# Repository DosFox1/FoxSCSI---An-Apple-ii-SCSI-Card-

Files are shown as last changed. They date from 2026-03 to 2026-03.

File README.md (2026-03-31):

# FoxSCSI - An Apple ii SCSI Card 
An open source clone of the Apple ii SCSI Card. Through hole and done in two layers!


(Many thanks to HKZ for testing this VDEV1 Prototype design)

Apple ii SCSI Low Res Top Side
Apple ii SCSI Low Res Bottom Side

# So what is it?

This is a recreation of the original Apple SCSI Rev C Card for the Apple II.
The equations for the SCSI card were found, converted to GALs, and tested with an original Rev C card.

Additionally, the schematics and ROM for the Rev C card are available online (added in this repository for completeness).
This board is two layer to reduce costs (five boards, finished in ENIG should be about £30 or £6 per board), and is fully through hole.
A 2.85v active termination voltage regulator is added but is not required. 

HKZ is working on an SMD variant of the SCSI card:
https://codeberg.org/hkzlab/AppleII_SCSI_RevC_schematics

# Note Regarding the Board Status
The initial VDEV1 board was tested by HKZ, and three issues were found:
1) a missing connection from IOSEL to the 74LS08
2) A missing "ghost" 330pf capacitor present on the actual boards, but not the transcribed schematics
3) Capacitors were initially noted to be 33pf, actual values should be 330pf.

With these changes, the board successfully booted a DELTA (Apple IIe clone using GALs in place of custom logic - https://codeberg.org/hkzlab/NE_Delta_Schematics).
The latest gerbers have fixes these issues, and should work as is. 

NOTE THAT THEY HAVE NOT BEEN BUILT YET. YOUR MILEAGE MAY VARY!

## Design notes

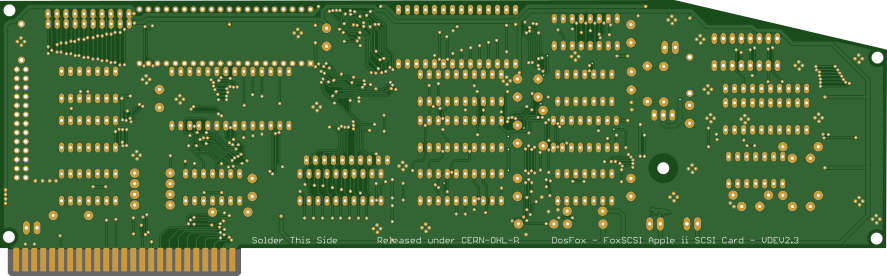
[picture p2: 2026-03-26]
Renders/Apple ii SCSI Low Res Bottom Side.png

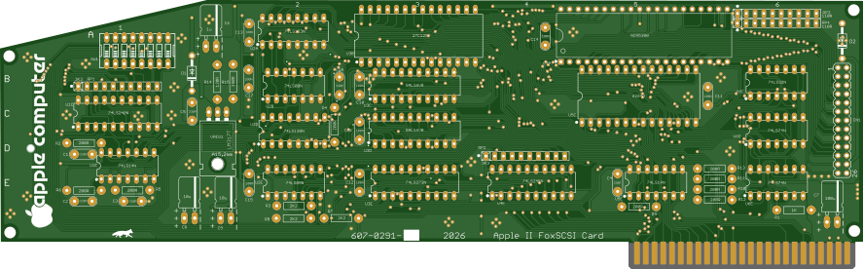
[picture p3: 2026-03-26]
Renders/Apple ii SCSI Low Res Top Side.png

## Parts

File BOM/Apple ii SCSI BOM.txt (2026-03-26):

Partlist

Exported from Apple ii SCSI VDEV2.sch at 25/Mar/26 09:02

EAGLE Version 9.6.2 Copyright (c) 1988-2020 Autodesk, Inc.

Assembly variant: 

Part     Value          Device                     Package               Library           Sheet

C1       330p 100V      330P_TH_CAP                 CAP_5.08MM_PITCH      Capacitors TH     1
C2       330p 100V      330P_TH_CAP                 CAP_5.08MM_PITCH      Capacitors TH     1
C3       330p 100V      330P_TH_CAP                 CAP_5.08MM_PITCH      Capacitors TH     1
C4       330p 100V      330P_TH_CAP                 CAP_5.08MM_PITCH      Capacitors TH     1
C5       330p 50V       330P_TH_CAP                CAP_5.08MM_PITCH      Capacitors TH     1
C6       1u 50V         1U_TH_ELEC_CAPHORIZONTAL   CAP_ELECTROLYTIC_FLAT Capacitors TH     1
C7       100U 50v       100U_TH_ELEC_CAPHORIZONTAL CAP_ELECTROLYTIC_FLAT Capacitors TH     1
C8       10U 50v        10U_TH_ELEC_CAPHORIZONTAL  CAP_ELECTROLYTIC_FLAT Capacitors TH     1
C9       10U 50v        10U_TH_ELEC_CAPHORIZONTAL  CAP_ELECTROLYTIC_FLAT Capacitors TH     1
C10      100n 50V       100N_TH_CAP                CAP_5.08MM_PITCH      Capacitors TH     1
C11      100n 50V       100N_TH_CAP                CAP_5.08MM_PITCH      Capacitors TH     1
C12      100n 50V       100N_TH_CAP                CAP_5.08MM_PITCH      Capacitors TH     1
C13      100n 50V       100N_TH_CAP                CAP_5.08MM_PITCH      Capacitors TH     1
C14      100n 50V       100N_TH_CAP                CAP_5.08MM_PITCH      Capacitors TH     1
C15      100n 50V       100N_TH_CAP                CAP_5.08MM_PITCH      Capacitors TH     1
C16      100n 50V       100N_TH_CAP                CAP_5.08MM_PITCH      Capacitors TH     1
C17      100n 50V       100N_TH_CAP                CAP_5.08MM_PITCH      Capacitors TH     1
C18      330p 100V      33P_TH_CAP                 CAP_5.08MM_PITCH      Capacitors TH     1
CN1      2x13 header    MA13-2                     MA13-2                con-lstb          1
D1       1N4004         1N4004                     DO41-10               adafruit          1
D2       1N4004         1N4004                     DO41-10               adafruit          1
R1       1k             1K_TH_RESISTOR             RESISTORTHRUHOLE      Resistors TH      1
R2       200R           200R_TH_RESISTOR           RESISTORTHRUHOLE      Resistors TH      1
R3       2k2            2K2_TH_RESISTOR            RESISTORTHRUHOLE      Resistors TH      1
R4       200R           200R_TH_RESISTOR           RESISTORTHRUHOLE      Resistors TH      1
R5       200R           200R_TH_RESISTOR           RESISTORTHRUHOLE      Resistors TH      1
R6       200R           200R_TH_RESISTOR           RESISTORTHRUHOLE      Resistors TH      1
R7       2k2            2K2_TH_RESISTOR            RESISTORTHRUHOLE      Resistors TH      1
R8       2k2            2K2_TH_RESISTOR            RESISTORTHRUHOLE      Resistors TH      1
R9       200R           200R_TH_RESISTOR           RESISTORTHRUHOLE      Resistors TH      1
R10      200R           200R_TH_RESISTOR           RESISTORTHRUHOLE      Resistors TH      1
R11      200R           200R_TH_RESISTOR           RESISTORTHRUHOLE      Resistors TH      1
R12      200R           200R_TH_RESISTOR           RESISTORTHRUHOLE      Resistors TH      1
R13      200R           200R_TH_RESISTOR           RESISTORTHRUHOLE      Resistors TH      1
R14      120R           120R_TH_RESISTOR           RESISTORTHRUHOLE      Resistors TH      1
R15      150R           150R_TH_RESISTOR           RESISTORTHRUHOLE      Resistors TH      1
RP1      3K3            RN09                       RN-10                 resistor-net      1
RP2      3K3            RN09                       RN-10                 resistor-net      1
RP3      100R           RN09                       RN-10                 resistor-net      1
RP4      100R           RN09                       RN-10                 resistor-net      1
SW1      8xDip Switch   DIP-08-PTH                 DIPSWITCH-08          SparkFun-Switches 1
U1C      74LS240N       74LS240N                   DIL20                 74xx-us           1
U1E      74LS14N        74LS14N                    DIL14                 74xx-us           1
U2A      74LS133N       74LS133N                   DIL16                 74xx-us           1
U2B      74LS08N        74LS08N                    DIL14                 74xx-us           1
U2D      74LS138N       74LS138N                   DIL16                 74xx-us           1
U2E      74LS09N        74LS09N                    DIL14                 74xx-us           1
U3B      27C128P        27C128P                    DIL28-6               microchip         1
U3C      GAL16V8        ATF16V8BP3                 DIL20                 atmel             1
U3D      GAL16V8        ATF16V8BP3                 DIL20                 atmel             1
U3E      74LS273N       74273N                     DIL20                 74xx-eu           1
U4E      74LS245N       74LS245N                   DIL20                 74xx-us           1
U5A      NCR5380        NCR5380                    DIP40                 ICs               1
U5C      6264A          6264A                      DIL28-6               memory-hitachi    1
U5E      74LS14N        74LS14N                    DIL14                 74xx-us           1
U6C      74LS32N        74LS32N                    DIL14                 74xx-us           1
U6D      74LS74N        74LS74N                    DIL14                 74xx-us           1
U6E      74LS74N        74LS74N                    DIL14                 74xx-us           1
VREG1    LM317T         LM317TL                    317TL                 v-reg             1

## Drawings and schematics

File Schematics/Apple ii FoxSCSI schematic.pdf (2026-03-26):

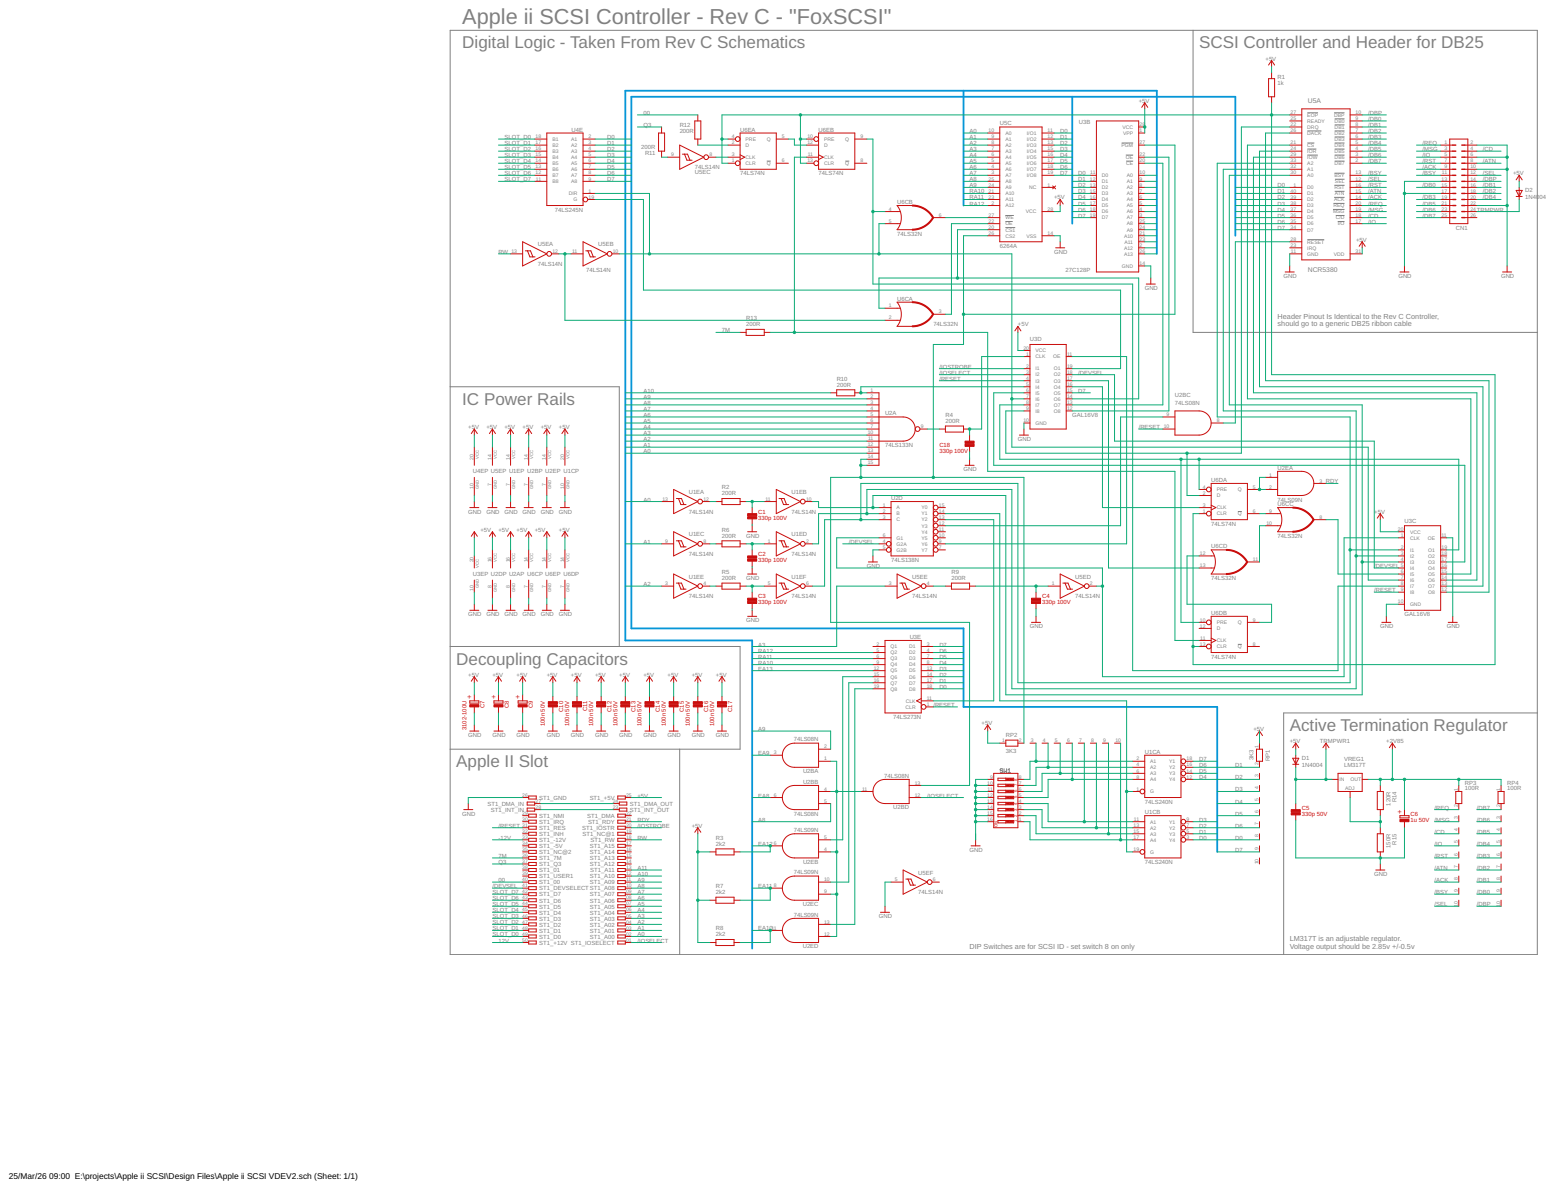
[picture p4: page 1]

Apple ii SCSI Controller - Rev C - "FoxSCSI"

Digital Logic - Taken From Rev C Schematics

SCSI Controller and Header for DB25

Header Pinout Is Identical to the Rev C Controller, should go to a generic DB25 ribbon cable

A4
A3 10

A1 12
13 A0

GND GND GND GND GND

GND GND GND

12 /IOSELECT | 11 | | 6

25/Mar/26 09:00 E:\projects\Apple ii SCSI\Design Files\Apple ii SCSI VDEV2.sch (Sheet: 1/1)

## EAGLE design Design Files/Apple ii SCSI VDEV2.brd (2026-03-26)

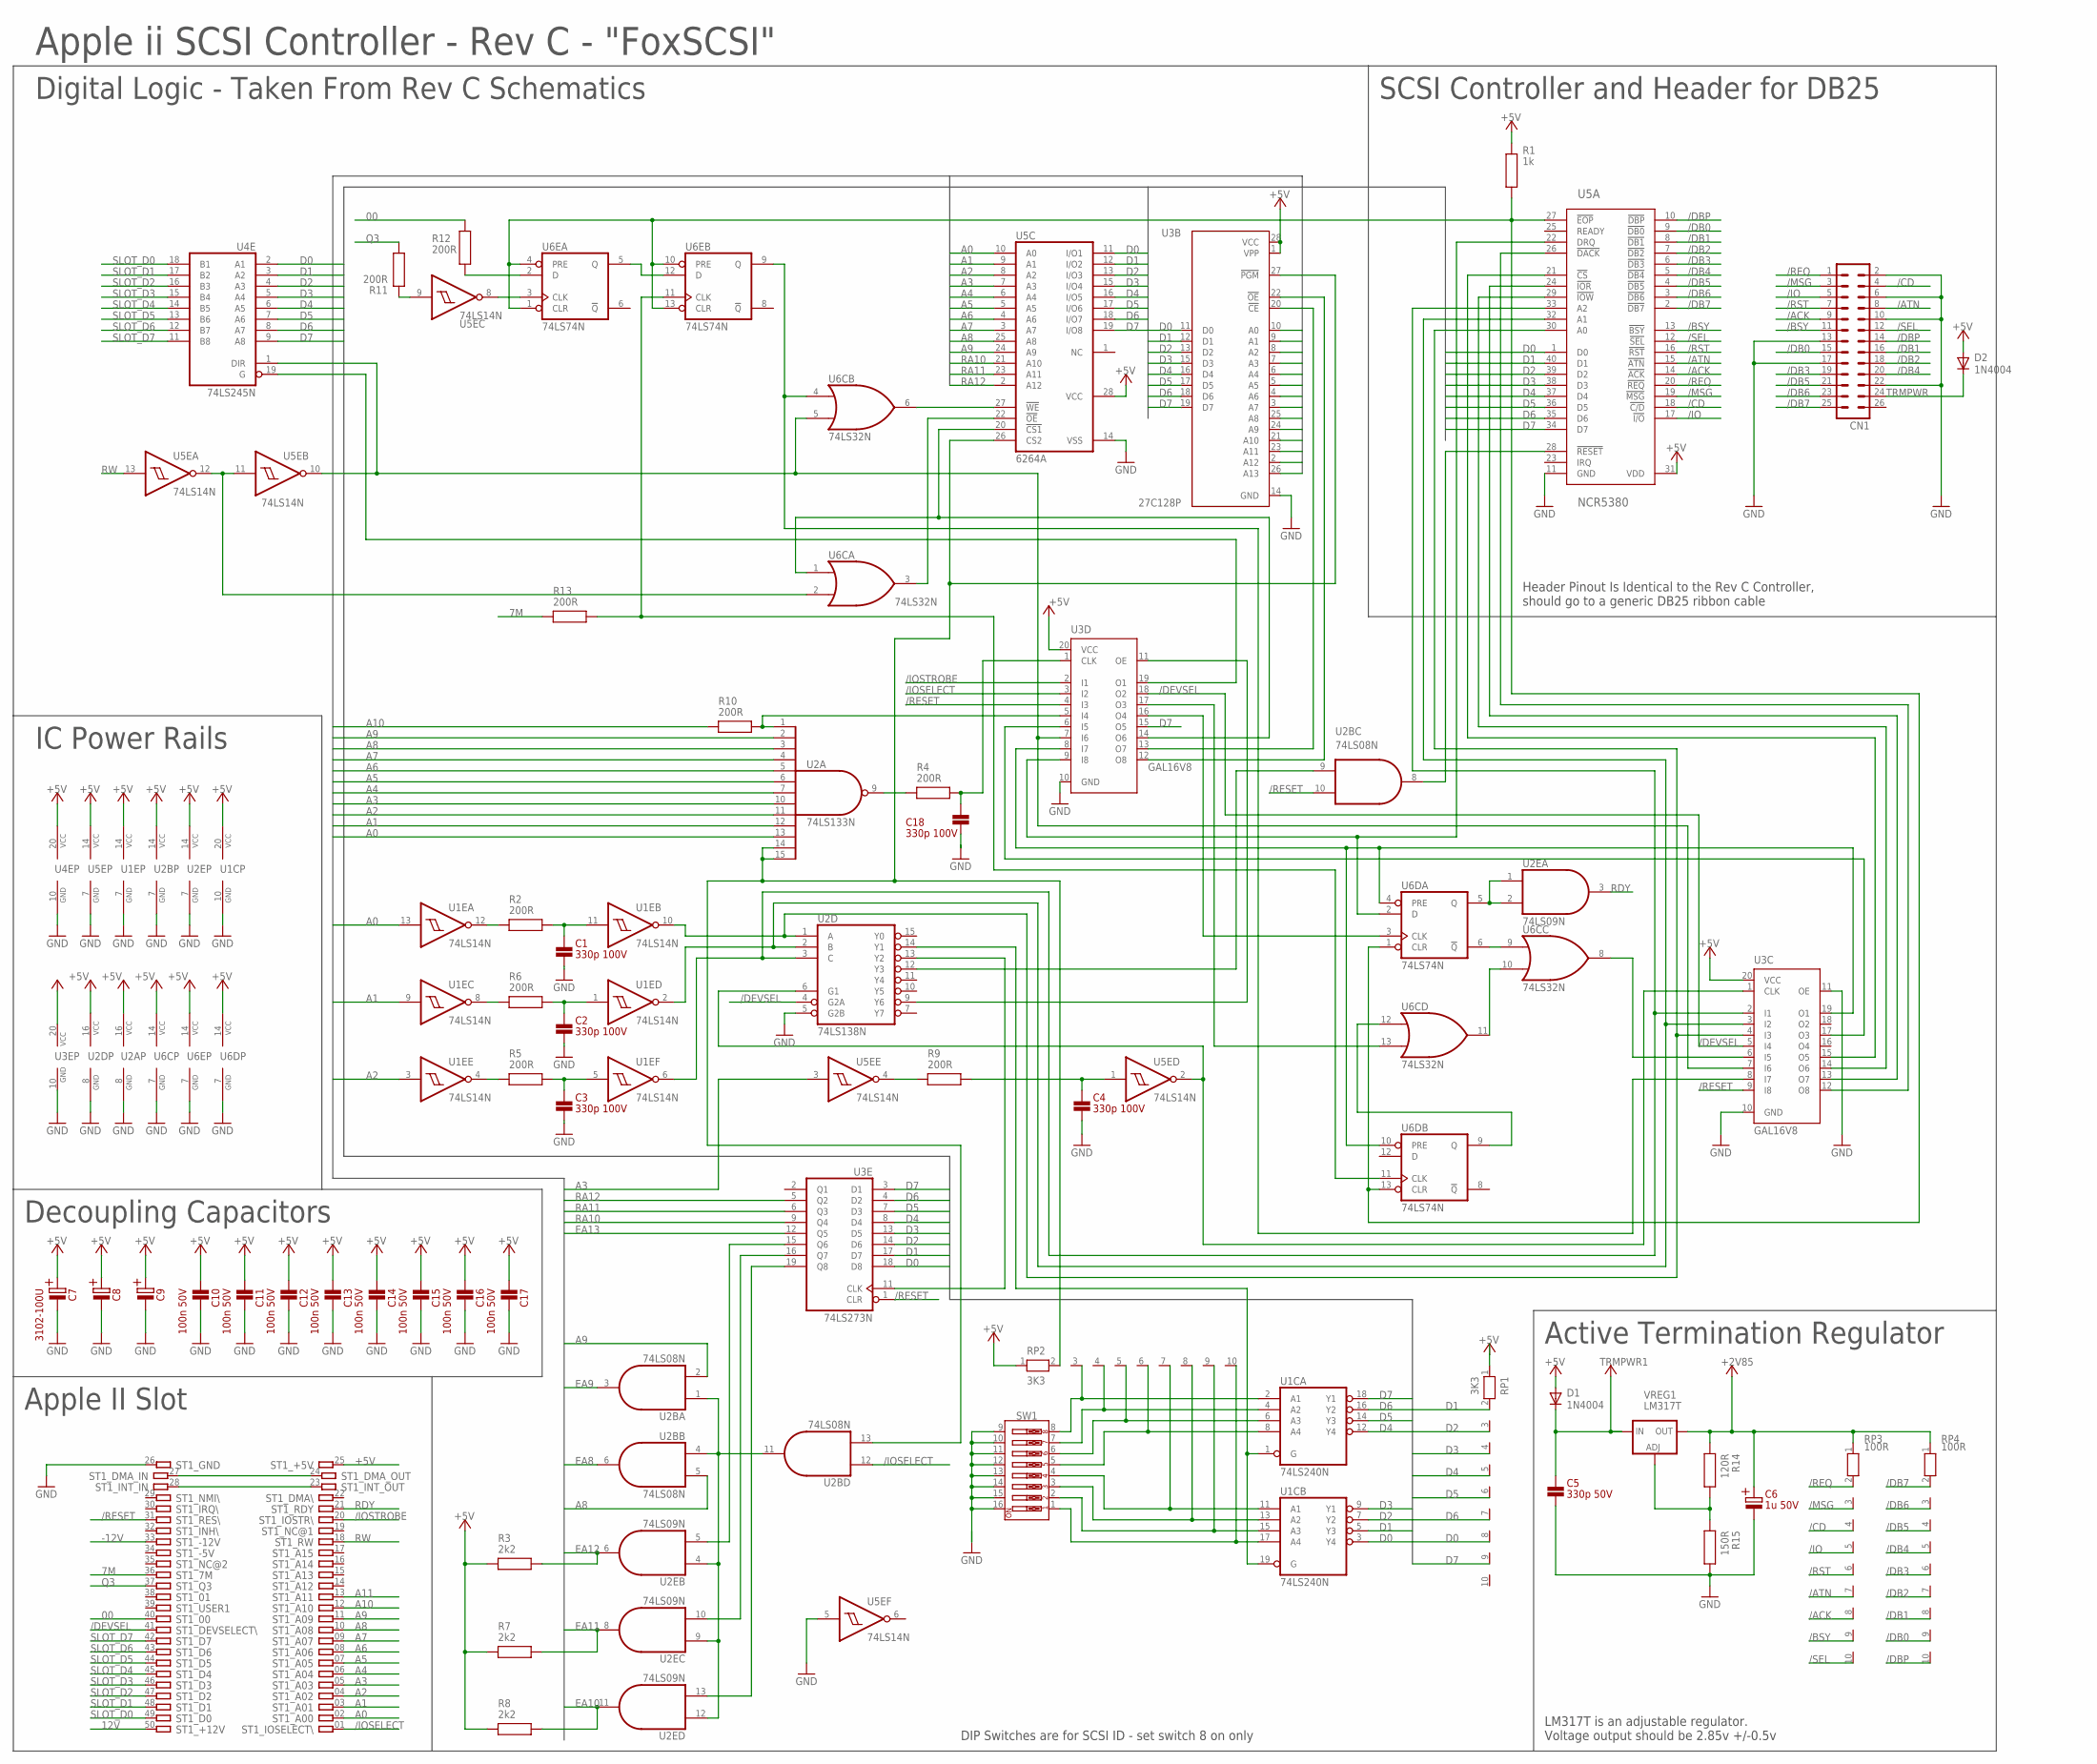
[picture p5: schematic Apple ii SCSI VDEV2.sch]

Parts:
C1, C2, C3, C4, C18: 330p 100V; CAP_5.08MM_PITCH
C5: 330p 50V; CAP_5.08MM_PITCH
C6: 1u 50V; CAP_ELECTROLYTIC_FLAT
C7: 3102-100U; CAP_ELECTROLYTIC_FLAT
C8, C9: 10U_TH_ELEC_CAPHORIZONTAL; CAP_ELECTROLYTIC_FLAT
C10, C11, C12, C13, C14, C15, C16, C17: 100n 50V; CAP_5.08MM_PITCH
CN1: MA13-2
D1, D2: 1N4004; DO41-10
R1: 1k; RESISTORTHRUHOLE
R2, R4, R5, R6, R9, R10, R11, R12, R13: 200R; RESISTORTHRUHOLE
R3, R7, R8: 2k2; RESISTORTHRUHOLE
R14: 120R; RESISTORTHRUHOLE
R15: 150R; RESISTORTHRUHOLE
RP1, RP2: 3K3; RN-10
RP3, RP4: 100R; RN-10
ST1: A2-50PINMINI; A2-50PIN-MINI
SW1: DIP-08-PTH; DIPSWITCH-08
U1C: 74LS240N; DIL20
U1E, U5E: 74LS14N; DIL14
U2A: 74LS133N; DIL16
U2B: 74LS08N; DIL14
U2D: 74LS138N; DIL16
U2E: 74LS09N; DIL14
U3B: 27C128P; DIL28-6
U3C, U3D: GAL16V8; DIL20
U3E: 74LS273N; DIL20
U4E: 74LS245N; DIL20
U5A: NCR5380; DIP40
U5C: 6264A; DIL28-6
U6C: 74LS32N; DIL14
U6D, U6E: 74LS74N; DIL14
VREG1: LM317T; 317TL

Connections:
00: R12.P$2, ST1.40
7M: R13.P$1, ST1.36
12V: ST1.50
+2V85: C6.P$1, R14.P$1, RP3.1, RP4.1, VREG1.2 (OUT)
+5V: C7.P$1, C8.P$1, C9.P$1, C10.P$1, C11.P$1, C12.P$1, C13.P$1, C14.P$1, C15.P$1, C16.P$1, C17.P$1, D1.A, D2.A, R1.P$2, R3.P$1, R7.P$1, R8.P$1, RP1.1, RP2.1, ST1.25, U1C.20 (VCC), U1E.14 (VCC), U2A.16 (VCC), U2B.14 (VCC), U2D.16 (VCC), U2E.14 (VCC), U3B.1 (VPP), U3B.28 (VCC), U3C.20 (VCC), U3D.20 (VCC), U3E.20 (VCC), U4E.20 (VCC), U5A.31 (VDD), U5C.28 (VCC), U5E.14 (VCC), U6C.14 (VCC), U6D.14 (VCC), U6E.14 (VCC)
-12V: ST1.33
/ACK: CN1.9, RP3.8, U5A.14 (!ACK)
/ATN: CN1.8, RP3.7, U5A.15 (!ATN)
/BSY: CN1.11, RP3.9, U5A.13 (!BSY)
/CD: CN1.4, RP3.4, U5A.18 (!C/D)
/DB0: CN1.15, RP4.9, U5A.9 (!DB0)
/DB1: CN1.16, RP4.8, U5A.8 (!DB1)
/DB2: CN1.18, RP4.7, U5A.7 (!DB2)
/DB3: CN1.19, RP4.6, U5A.6 (!DB3)
/DB4: CN1.20, RP4.5, U5A.5 (!DB4)
/DB5: CN1.21, RP4.4, U5A.4 (!DB5)
/DB6: CN1.23, RP4.3, U5A.3 (!DB6)
/DB7: CN1.25, RP4.2, U5A.2 (!DB7)
/DBP: CN1.14, RP4.10, U5A.10 (!DBP)
/DEVSEL: ST1.41, U2D.4 (G2A), U3C.5 (I4), U3D.18 (O2)
/IO: CN1.5, RP3.5, U5A.17 (!I/O)
/IOSELECT: ST1.01, U2B.12 (I0), U3D.3 (I2)
/IOSTROBE: ST1.20, U3D.2 (I1)
/MSG: CN1.3, RP3.3, U5A.19 (!MSG)
/REQ: CN1.1, RP3.2, U5A.20 (!REQ)
/RESET: ST1.31, U2B.10 (I1), U3C.9 (I8), U3D.4 (I3), U3E.1 (CLR)
/RST: CN1.7, RP3.6, U5A.16 (!RST)
/SEL: CN1.12, RP3.10, U5A.12 (!SEL)
A0: ST1.02, U1E.13 (I), U2A.13 (I10), U3B.10 (A0), U5C.10 (A0)
A1: ST1.03, U1E.9 (I), U2A.12 (I9), U3B.9 (A1), U5C.9 (A1)
A2: ST1.04, U1E.3 (I), U2A.11 (I8), U3B.8 (A2), U5C.8 (A2)
A3: ST1.05, U2A.10 (I7), U3B.7 (A3), U5C.7 (A3), U5E.3 (I)
A4: ST1.06, U2A.7 (I6), U3B.6 (A4), U5C.6 (A4)
A5: ST1.07, U2A.6 (I5), U3B.5 (A5), U5C.5 (A5)
A6: ST1.08, U2A.5 (I4), U3B.4 (A6), U5C.4 (A6)
A7: ST1.09, U2A.4 (I3), U3B.3 (A7), U5C.3 (A7)
A8: ST1.10, U2A.3 (I2), U2B.5 (I1), U5C.25 (A8)
A9: ST1.11, U2A.2 (I1), U2B.2 (I1), U5C.24 (A9)
A10: R10.P$1, ST1.12
A11: ST1.13
D0: RP1.8, U1C.3 (Y4), U3B.11 (D0), U3E.18 (D8), U4E.2 (A1), U5A.1 (D0), U5C.11 (I/O1)
D1: RP1.2, U1C.5 (Y3), U3B.12 (D1), U3E.17 (D7), U4E.3 (A2), U5A.40 (D1), U5C.12 (I/O2)
D2: RP1.3, U1C.7 (Y2), U3B.13 (D2), U3E.14 (D6), U4E.4 (A3), U5A.39 (D2), U5C.13 (I/O3)
D3: RP1.4, U1C.9 (Y1), U3B.15 (D3), U3E.13 (D5), U4E.5 (A4), U5A.38 (D3), U5C.15 (I/O4)
D4: RP1.5, U1C.12 (Y4), U3B.16 (D4), U3E.8 (D4), U4E.6 (A5), U5A.37 (D4), U5C.16 (I/O5)
D5: RP1.6, U1C.14 (Y3), U3B.17 (D5), U3E.7 (D3), U4E.7 (A6), U5A.36 (D5), U5C.17 (I/O6)
D6: RP1.7, U1C.16 (Y2), U3B.18 (D6), U3E.4 (D2), U4E.8 (A7), U5A.35 (D6), U5C.18 (I/O7)
D7: RP1.9, U1C.18 (Y1), U3B.19 (D7), U3D.15 (O5), U3E.3 (D1), U4E.9 (A8), U5A.34 (D7), U5C.19 (I/O8)
EA8: U2B.6 (O), U3B.25 (A8)
EA9: U2B.3 (O), U3B.24 (A9)
EA10: R8.P$2, U2E.11 (O), U3B.21 (A10)
EA11: R7.P$2, U2E.8 (O), U3B.23 (A11)
EA12: R3.P$2, U2E.6 (O), U3B.2 (A12)
EA13: U3B.26 (A13), U3E.12 (Q5)
GND: C1.P$1, C2.P$1, C3.P$1, C4.P$1, C5.P$1, C6.P$2, C7.P$2, C8.P$2, C9.P$2, C10.P$2, C11.P$2, C12.P$2, C13.P$2, C14.P$2, C15.P$2, C16.P$2, C17.P$2, C18.P$1, CN1.2, CN1.6, CN1.10, CN1.13, CN1.17, CN1.22, R15.P$2, ST1.26, SW1.9, SW1.10, SW1.11, SW1.12, SW1.13, SW1.14, SW1.15, SW1.16, U1C.10 (GND), U1E.7 (GND), U2A.8 (GND), U2B.7 (GND), U2D.5 (G2B), U2D.8 (GND), U2E.7 (GND), U3B.14 (GND), U3C.10 (GND), U3C.11 (OE), U3D.10 (GND), U3E.10 (GND), U4E.10 (GND), U5A.11 (GND), U5C.14 (VSS), U5E.5 (I), U5E.7 (GND), U6C.7 (GND), U6D.7 (GND), U6E.7 (GND)
unnamed: ST1.24, ST1.27
unnamed: ST1.23, ST1.28
unnamed: U5E.11 (I), U5E.12 (O), U6C.2 (I1)
unnamed: U2B.8 (O), U5A.28 (!RESET)
unnamed: RP2.3, SW1.8, U1C.2 (A1)
unnamed: RP2.4, SW1.7, U1C.4 (A2)
unnamed: RP2.5, SW1.6, U1C.6 (A3)
unnamed: RP2.6, SW1.5, U1C.8 (A4)
unnamed: RP2.7, SW1.4, U1C.11 (A1)
unnamed: RP2.8, SW1.3, U1C.13 (A2)
unnamed: RP2.9, SW1.2, U1C.15 (A3)
unnamed: RP2.10, SW1.1, U1C.17 (A4)
unnamed: U2E.13 (I1), U3E.19 (Q8)
unnamed: U2B.1 (I0), U2B.4 (I0), U2B.11 (O), U2E.4 (I0), U2E.9 (I0), U2E.12 (I0)
unnamed: U2E.10 (I1), U3E.16 (Q7)
unnamed: U2E.5 (I1), U3E.15 (Q6)
unnamed: U1E.10 (O), U2D.1 (A), U3C.4 (I3), U5A.30 (A0)
unnamed: U1E.2 (O), U2D.2 (B), U3C.3 (I2), U5A.32 (A1)
unnamed: C18.P$2, R4.P$2, U3D.1 (CLK)
unnamed: C1.P$2, R2.P$2, U1E.11 (I)
unnamed: R2.P$1, U1E.12 (O)
unnamed: R6.P$1, U1E.8 (O)
unnamed: C2.P$2, R6.P$2, U1E.1 (I)
unnamed: C3.P$2, R5.P$2, U1E.5 (I)
unnamed: R5.P$1, U1E.4 (O)
unnamed: R9.P$1, U5E.4 (O)
unnamed: C4.P$2, R9.P$2, U5E.1 (I)
unnamed: R4.P$1, U2A.9 (O)
unnamed: R10.P$2, U2A.1 (I0), U3D.5 (I4)
unnamed: U1E.6 (O), U2D.3 (C), U3C.2 (I1), U5A.33 (A2)
unnamed: U3C.17 (O3), U3D.6 (I5)
unnamed: U3C.8 (I7), U6C.4 (I0), U6E.9 (Q)
unnamed: U3C.19 (O1), U3D.8 (I7), U6D.4 (PRE), U6D.10 (PRE)
unnamed: U3D.9 (I8), U5A.22 (DRQ), U6D.2 (D)
unnamed: U2D.9 (Y6), U3D.11 (OE)
unnamed: U3B.22 (!OE), U3D.12 (O8)
unnamed: U3B.20 (!CE), U3D.13 (O7)
unnamed: U3D.14 (O6), U5C.20 (!CS1), U6C.1 (I0)
unnamed: U3D.16 (O4), U6D.3 (CLK)
unnamed: U3D.17 (O3), U6C.13 (I1)
unnamed: U3D.19 (O1), U4E.19 (G)
unnamed: U2D.6 (G1), U3C.1 (CLK), U5E.2 (O)
unnamed: U2D.13 (Y2), U3E.11 (CLK)
unnamed: U2B.9 (I0), U2D.12 (Y3)
unnamed: U1C.1 (G), U1C.19 (G), U2D.14 (Y1)
unnamed: U2E.1 (I0), U2E.2 (I1), U6D.5 (Q)
unnamed: U3C.6 (I5), U6C.8 (O)
unnamed: U6C.9 (I0), U6D.6 (!Q)
unnamed: U6C.10 (I1), U6C.11 (O)
unnamed: U6C.12 (I0), U6D.9 (Q)
unnamed: R1.P$1, U5A.27 (!EOP), U6D.1 (CLR), U6D.13 (CLR), U6E.1 (CLR), U6E.4 (PRE), U6E.10 (PRE), U6E.13 (CLR)
unnamed: R13.P$2, U6D.11 (CLK), U6E.11 (CLK)
unnamed: R11.P$2, U5E.9 (I)
unnamed: U3C.14 (O6), U5A.29 (!IOW)
unnamed: U3C.13 (O7), U5A.24 (!IOR)
unnamed: U3C.12 (O8), U5A.26 (!DACK)
unnamed: U3C.7 (I6), U3D.7 (I6), U4E.1 (DIR), U5E.10 (O), U6C.5 (I1)
unnamed: U3C.15 (O5), U5A.21 (!CS)
unnamed: U5E.8 (O), U6E.3 (CLK)
unnamed: R12.P$1, U6E.2 (D)
unnamed: U6E.5 (Q), U6E.12 (D)
unnamed: U5C.27 (!WE), U6C.6 (O)
unnamed: U5C.22 (!OE), U6C.3 (O)
unnamed: RP2.2, U2A.14 (I11), U2A.15 (I12), U2B.13 (I1), U3B.27 (!PGM), U5C.26 (CS2)
unnamed: R14.P$2, R15.P$1, VREG1.1 (ADJ)
Q3: R11.P$1, ST1.37
RA10: U3E.9 (Q4), U5C.21 (A10)
RA11: U3E.6 (Q3), U5C.23 (A11)
RA12: U3E.5 (Q2), U5C.2 (A12)
RDY: ST1.21, U2E.3 (O)
RW: ST1.18, U5E.13 (I)
SLOT_D0: ST1.49, U4E.18 (B1)
SLOT_D1: ST1.48, U4E.17 (B2)
SLOT_D2: ST1.47, U4E.16 (B3)
SLOT_D3: ST1.46, U4E.15 (B4)
SLOT_D4: ST1.45, U4E.14 (B5)
SLOT_D5: ST1.44, U4E.13 (B6)
SLOT_D6: ST1.43, U4E.12 (B7)
SLOT_D7: ST1.42, U4E.11 (B8)
TRMPWR: CN1.24, D2.C
TRMPWR1: C5.P$2, D1.C, VREG1.3 (IN)

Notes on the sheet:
Apple ii SCSI Controller - Rev C - "FoxSCSI"
Digital Logic - Taken From Rev C Schematics
Apple II Slot
Active Termination Regulator
SCSI Controller and Header for DB25
Header Pinout Is Identical to the Rev C Controller, should go to a generic DB25 ribbon cable
LM317T is an adjustable regulator. Voltage output should be 2.85v +/-0.5v
DIP Switches are for SCSI ID - set switch 8 on only
Decoupling Capacitors
IC Power Rails

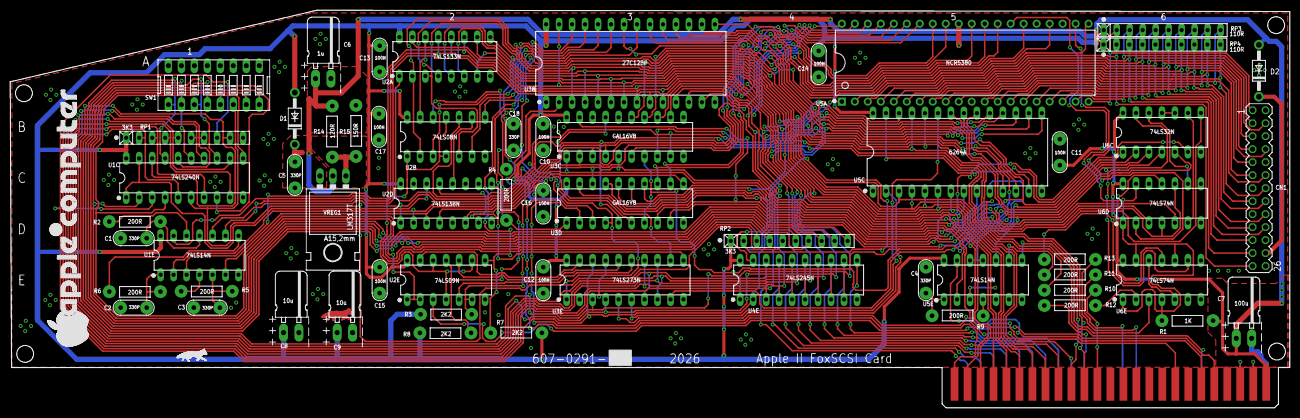
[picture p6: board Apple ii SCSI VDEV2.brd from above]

Board: 2 copper layers, 250.3 x 77.8 mm, 60 parts (0 on the bottom side), 133 nets.

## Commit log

2026-03-26 Rename Apple ii FoxSCSI Gerbers VDEV2.3 JLCPCB.zip to Gerbers/Apple ii FoxSCSI Gerbers VDEV2.3 JLCPCB.zip
2026-03-26 Rename Rev. C SCSI Schematic.jpg to Schematics/Rev. C SCSI Schematic.jpg
2026-03-26 Rename Apple ii FoxSCSI schematic.pdf to Schematics/Apple ii FoxSCSI schematic.pdf
2026-03-26 Rename Apple ii SCSI BOM.txt to BOM/Apple ii SCSI BOM.txt
2026-03-26 Rename Apple ii SCSI VDEV2.brd to Design Files/Apple ii SCSI VDEV2.brd
    [Apple ii SCSI VDEV2.brd]
2026-03-26 Rename Apple ii SCSI VDEV2.sch to Design Files/Apple ii SCSI VDEV2.sch
    [Apple ii SCSI VDEV2.sch]

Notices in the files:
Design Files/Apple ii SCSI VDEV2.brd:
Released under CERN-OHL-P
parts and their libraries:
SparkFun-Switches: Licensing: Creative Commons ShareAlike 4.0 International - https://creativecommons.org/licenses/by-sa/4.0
